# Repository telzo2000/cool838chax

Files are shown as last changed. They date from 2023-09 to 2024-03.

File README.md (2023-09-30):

# cool838chax

cool838chax is a small keyboard. 
<br>
This keyboard has 38 keys. 
<br>
cool838chax is an Alice layout. 
<br>
cool838chax use RP2040-Zero,run QMK_firmware.
<br>
cool838chax is cool838ax with choc switch and narrow key layout.
<br>

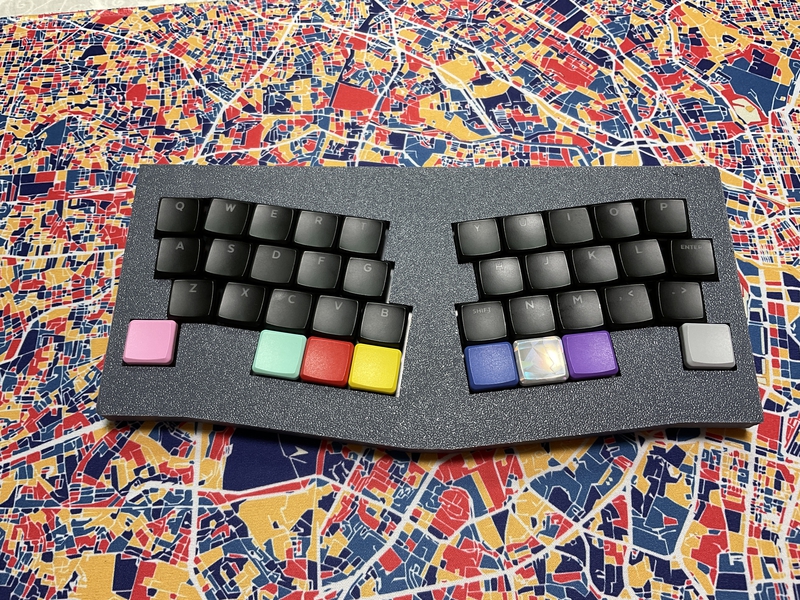
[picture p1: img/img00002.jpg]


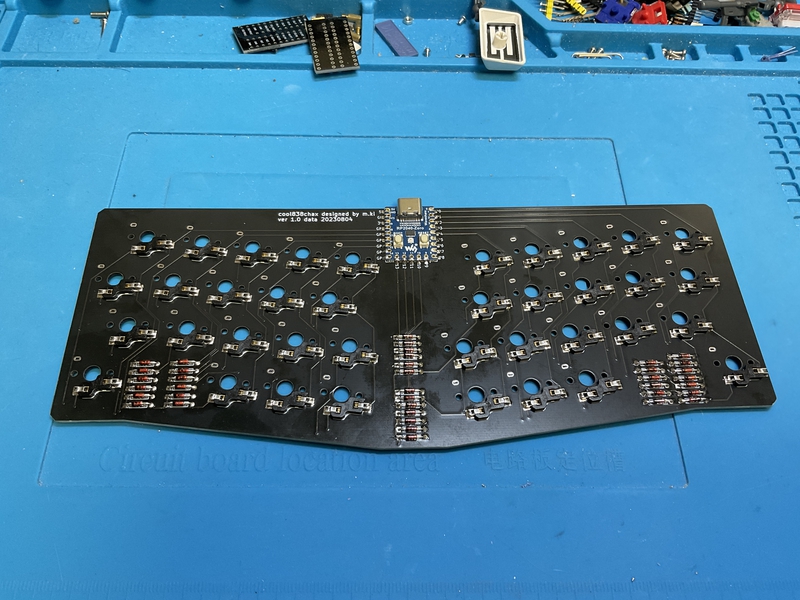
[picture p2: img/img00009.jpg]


And,this is cool838chax-db using RP2040-Tiny.
<br>

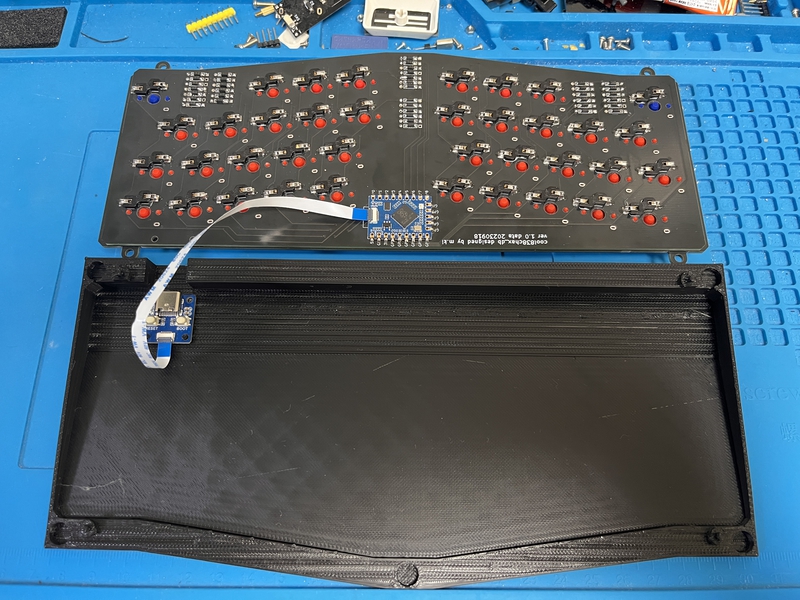
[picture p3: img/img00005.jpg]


## Firmware

The same thing as cool838ax and cool838chax-db can be used.
<br>
[Here](https://github.com/telzo2000/cool838ax/tree/main/firmware)

<br>

cool838chax and cool838chax-db are the same in design as [cool838ax](https://github.com/telzo2000/cool838ax). The difference is the key switch.
<br>

cool838chaxとcool838chax-dbは、[cool838ax](https://github.com/telzo2000/cool838ax)と設計上、同じものです。違いはキースイッチです。
<br>

## Buildguide

https://github.com/telzo2000/cool838chax/blob/main/buildguide_for_cool838chax.md

## Parts list

### For cool838chax
| No. | Patrs | Quantity | remarks | Suppliers | Cost |
|--|--|--|--|--|--|
|番号|名前|数|備考|調達先|参考価格（送料込）|<br>
|1|PCB|1|38key AlicLayout|[elecrow](https://www.elecrow.com)<br>[JLCPCB](https://jlcpcb.com)<br>[ALLPCB](https://www.allpcb.com)|５枚で20〜30ドル|<br>
|2|Switch Plate|1||[elecrow](https://www.elecrow.com)<br>[JLCPCB](https://jlcpcb.com)<br>[ALLPCB](https://www.allpcb.com)|５枚で20〜30ドル|<br>
|3|RP2040-Zero|1||[Talp Keyboard](https://talpkeyboard.net)|800円|
|4|Swith socket<br>スイッチソケット|38|shoc|[遊舎工房](https://yushakobo.jp)<br>[Talp Keyboard](https://talpkeyboard.net)<br>[Daily Craft Keyboard](https://shop.dailycraft.jp)等|10個で165円程度|
|5|Diode<br>ダイオード|38|SMDを推奨|[遊舎工房](https://yushakobo.jp)<br>[Talp Keyboard](https://talpkeyboard.net)<br>[Daily Craft Keyboard](https://shop.dailycraft.jp)等|100個で220円程度から|
|6|TopCase|1|3D Print|||
|7|BottomCase|1|3D Print||

### For cool838chax-db
| No. | Patrs | Quantity | remarks | Suppliers | Cost |
|--|--|--|--|--|--|
|番号|名前|数|備考|調達先|参考価格（送料込）|<br>
|1|PCB|1|38key AlicLayout|[elecrow](https://www.elecrow.com)<br>[JLCPCB](https://jlcpcb.com)<br>[ALLPCB](https://www.allpcb.com)|５枚で20〜30ドル|<br>
|2|Switch Plate|1||[elecrow](https://www.elecrow.com)<br>[JLCPCB](https://jlcpcb.com)<br>[ALLPCB](https://www.allpcb.com)|５枚で20〜30ドル|<br>
|3|RP2040-Tiny|1||[スイッチサイエンス](https://www.switch-science.com/products/9092)|891円|
|4|Swith socket<br>スイッチソケット|38|shoc|[遊舎工房](https://yushakobo.jp)<br>[Talp Keyboard](https://talpkeyboard.net)<br>[Daily Craft Keyboard](https://shop.dailycraft.jp)等|10個で165円程度|
|5|Diode<br>ダイオード|38|SMDを推奨|[遊舎工房](https://yushakobo.jp)<br>[Talp Keyboard](https://talpkeyboard.net)<br>[Daily Craft Keyboard](https://shop.dailycraft.jp)等|100個で220円程度から|
|6|TopCase|1|3D Print|||
|7|BottomCase|1|3D Print||

In addition, you will need a USB cable, keycaps, etc.
<br>
この他に、USBケーブル、キーキャップ等が必要です。
<br>

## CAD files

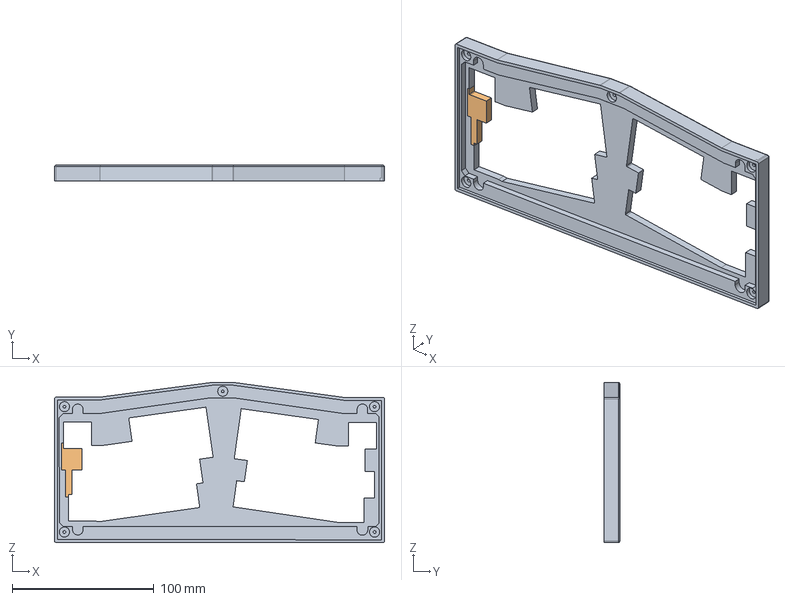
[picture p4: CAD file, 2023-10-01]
case_design/cool838chax-db/step/cool838chax_db_casedesign_top v2.step
233.0 x 11.0 x 113.2 mm

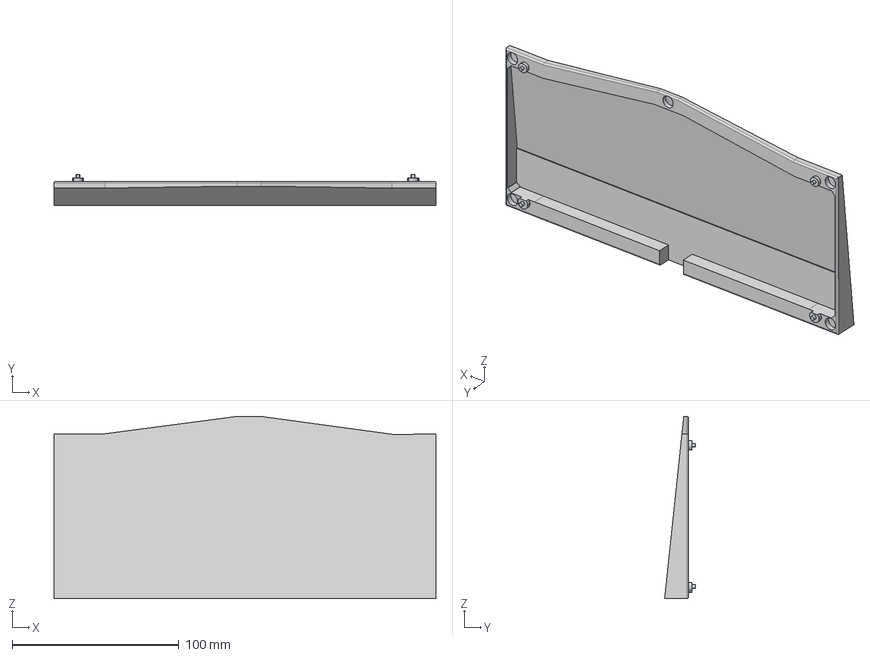
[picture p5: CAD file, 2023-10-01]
case_design/cool838chax/step/cool838chax_casedesign_bottom v5.step
229.0 x 18.5 x 109.2 mm

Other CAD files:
case_design/cool838chax-db/step/cool838chax_db_casedesign_bottom v6.step
case_design/cool838chax/step/cool838chax_casedesign_top v10.step
case_design/cool838chax-db/stl/cool838chax_db_casedesign_bottom v6.stl
case_design/cool838chax-db/stl/cool838chax_db_casedesign_top v2.stl
case_design/cool838chax/stl/cool838chax_casedesign_bottom v5.stl
case_design/cool838chax/stl/cool838chax_casedesign_top v10.stl

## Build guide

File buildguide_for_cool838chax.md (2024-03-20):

## Build guide

## Firmware

###  QMK_FIRMWARE

参考<br>

https://github.com/telzo2000/Hello_keyboard/blob/main/readme_about_firmware.md

[Here](https://github.com/telzo2000/cool838ax/tree/main/firmware)

<br>

[remap](https://remap-keys.app/catalog/pLXvG6i1dYtpbWD7ujzv)

<br>

## Build 1

### 1 Diode soldering

Solder the diodes to the back of PCB.
<br>
PCBの裏面にダイオードのハンダ付けをします。
<br>
There are lead type and SMD diodes.
<br>
ダイオードはリードタイプか、SMDがあります。

<br>
cool838chax uses choc switches, so the distance between the switch plate and the PCB is narrow.
<br>
cool838chaxは、chocスイッチを使用しているため、スイッチプレートとPCBとの間隔が狭いです。
<br>
It is recommended to use SMD rather than lead type.
<br>
リードタイプを使用するよりも、SMDを使用することを推奨します。
<br>
If you use a lead type, cut the protruding legs short.
<br>
もし、リードタイプを使用する場合、はみ出た足を短く切り取ってください。
<br>

[８倍速　Diodeハンダ付け動画](https://youtu.be/Yaodh2-XxV4)

<br>
<br>

### 2 Soldering switch sockets

Solder the switch sockets on the back side.
<br>
裏面にスイッチソケットのハンダ付けをします。
<br>

[８倍速　Switch socketハンダ付け動画](https://youtu.be/E__mHvmIXQo)

<br><br>

### 3a　Soldering RP2040-Zero (cool838chax) 

The side on which the RP2040-Zero components are mounted is the front side, and the opposite side is the back side.
<br>
RP2040-Zeroの部品実装されている面を表面とし、反対側を裏面とします。
<br>
Place the back side of the PCB and the back side of the RP2040-Zero facing each other and solder the respective terminals.
<br>
PCBの裏面とRP2040-Zeroの裏面が向かい合うようにして置き、それぞれの端子をハンダ付けします。
<br>



<br>

### 3b Soldering RP2040-Tiny (cool838chax-db)

The side on which the RP2040-Tiny components are mounted is the front side, and the opposite side is the back side.
<br>
RP2040-Tinyの部品実装されている面を表面とし、反対側を裏面とします。
<br>
Place the back side of the PCB and the back side of the RP2040-Tiny facing each other and solder the respective terminals.
<br>
PCBの裏面とRP2040-Tinyの裏面が向かい合うようにして置き、それぞれの端子をハンダ付けします。
<br>
At this point, we will not attach it to the adapter board yet.
<br>
ここでは、まだアダプタ基板との取り付けはしません。
<br>

### 4 Instorlling QMK＿Firmware

Install QMK_Firmware from your PC to RP2040-Zero.
<br>
QMK_FirmwareをPCからRP2040-Zeroにインストールしてください。
<br>
<br>
① Download https://github.com/telzo2000/cool838ax/blob/main/firmware/cool838ax_via.uf2　to your PC.
<br>
①https://github.com/telzo2000/cool838ax/blob/main/firmware/cool838ax_via.uf2　をPCにダウンロードしておく。

<br><br>
② Connect the PC and RP2040-Zero with a USB cable.
<br>
②PCとRP2040-ZeroをUSBケーブルで繋ぐ。
<br><br>
③Press the reset button while pressing the boost button on the RP2040-Zero.
<br>
③RP2040-Zeroのboostボタン押しながら、resetボタンを押す。
<br><br>
④Since there is a folder of RP2040-Zero on the PC screen, drag and drop the downloaded cool838ax.uf2 there.
<br>
④PC画面にはRP2040-Zeroのフォルダがあるので、そこに、ダウンロードしたcool838ax.uf2をドラッグアンドドロップする。
<br><br>

⑤Check if it is recognized by connecting to remap. Edit the keymap accordingly.
<br>
⑤remapに繋いで認識するかどうか確認する。合わせてキーマップの編集をする。

### Build 2(case)

### 1 Case (cool838chax)

I will explain using a case printed by stereolithography of black resin ordered from JLCPCB. The procedure is basically the same for cases printed with Ankemake M5 for home use.
<br>
JLCPCBに発注したブラックレジンの光造形で印刷されたケースを使って説明します。家庭用AnkemakeM5で印刷したケースでも作業の手順は、基本的に同じです。
<br>
<br>
Fix the magnets to the five dents inside the case with an adhesive or the like. There are ５ in the top case and ５ in the bottom case for a total of １０.Please pay attention to the polarity of the magnet. Make sure the top case and bottom case are magnetically attached.
<br>
ケースの内側にある５つの凹みに磁石を接着剤などで固定します。トップケースに５箇所、ボトムケースに５箇所の合計１０箇所です。
極性に注意してください。トップケースとボトムケースが磁力で着くようにしてください。
<br>

As shown in the image below, attach rubber O-rings to the four protrusions on the bottom case. This makes it a gasket mount. You can do without the O-ring, but the PCB may move up and down inside the case.
<br>
下の画像のように、ボトムケースに4箇所の凸部にゴムのO-ringを装着します。これによりガスケットマウントとなります。O-ringはなくても大丈夫ですが、ケース内で、PCBが上下に動く可能性があります。
<br>

The O-ring is [this product](https://www.amazon.co.jp/gp/product/B07G4SM5SM/ref=ppx_yo_dt_b_asin_title_o03_s00?ie=UTF8&psc=1).
<br>
O-ringは[この商品](https://www.amazon.co.jp/gp/product/B07G4SM5SM/ref=ppx_yo_dt_b_asin_title_o03_s00?ie=UTF8&psc=1)です。
<br>
<br>
Place the hole in the switch plate on the O-ring. And it is completed by covering the top case.
<br>
スイッチプレートの穴をO-ringに載せます。そして、トップケースを被せて完成です。
<br>

### 1 Case (cool838chax-db)

I will explain using a case printed by stereolithography of black resin ordered from JLCPCB. The procedure is basically the same for cases printed with Ankemake M5 for home use.
<br>
JLCPCBに発注したブラックレジンの光造形で印刷されたケースを使って説明します。家庭用AnkemakeM5で印刷したケースでも作業の手順は、基本的に同じです。
<br>
<br>
Fix the magnets to the five dents inside the case with an adhesive or the like. There are ５ in the top case and ５ in the bottom case for a total of １０.Please pay attention to the polarity of the magnet. Make sure the top case and bottom case are magnetically attached.
<br>
ケースの内側にある５つの凹みに磁石を接着剤などで固定します。トップケースに５箇所、ボトムケースに５箇所の合計１０箇所です。
極性に注意してください。トップケースとボトムケースが磁力で着くようにしてください。
<br>
Attach the RP2040-Tiny adapter board to the bottom case. Make sure that the four holes on the adapter board match the four protrusions on the bottom base.
<br>
ボトムケースにRP2040-Tinyのアダプタ基板を取り付けます。アダプタ基板の４つの穴とボトムのースの４つの突起が組み合わさるようにしてください。
<br>
The protrusions are very thin and break easily. If you are worried, please fix the adapter board and bottom case with double-sided tape.
<br>
突起はとても、細く、折れやすいです。心配ならば、アダプタ基板とボトムケースを両面テープで、固定してください。
<br>
Next, connect the adapter board and RP2040-Tiny with the FPC cable. Be careful of the cable orientation.
<br>
次に、アダプタ基板とRP2040-TinyをFPCケーブルで接続してください。ケーブルの向きに注意してください。
<br>



Now run 4 Installing QMK_Firmware.
<br>
ここで、4 Instorlling QMK＿Firmwareを実行してください。
<br>
<br>
As shown in the image below, attach rubber O-rings to the four protrusions on the bottom case. This makes it a gasket mount. You can do without the O-ring, but the PCB may move up and down inside the case.
<br>
下の画像のように、ボトムケースに4箇所の凸部にゴムのO-ringを装着します。これによりガスケットマウントとなります。O-ringはなくても大丈夫ですが、ケース内で、PCBが上下に動く可能性があります。
<br>

The O-ring is [this product](https://www.amazon.co.jp/gp/product/B07G4SM5SM/ref=ppx_yo_dt_b_asin_title_o03_s00?ie=UTF8&psc=1).
<br>
O-ringは[この商品](https://www.amazon.co.jp/gp/product/B07G4SM5SM/ref=ppx_yo_dt_b_asin_title_o03_s00?ie=UTF8&psc=1)です。
<br>
<br>
Place the hole in the switch plate on the O-ring. And it is completed by covering the top case.
<br>
スイッチプレートの穴をO-ringに載せます。そして、トップケースを被せて完成です。
<br>

Welcome to the world of 38 keys.
<br>
38キーの世界へようこそ。
<br>
